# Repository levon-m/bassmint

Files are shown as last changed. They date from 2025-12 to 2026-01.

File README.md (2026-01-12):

# BassMINT

Bass (M)ount for (I)nfrared (N)ote (T)ranscription is a device built with the Teensy 4.0 that slides onto your bass guitar bridge and streams monophonic tablature in real-time via MIDI. This information can be utilized by software like DAW plugins to create practice, transcription, or education tools. The device currently only supports 4-string bass guitars with the Fender Jazz-style bridge, with up to 24 frets.

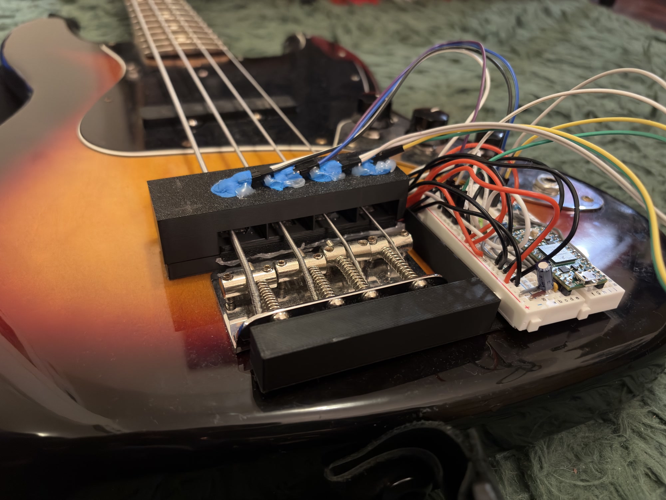
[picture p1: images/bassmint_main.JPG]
BassMINT Device


## Why?

Bass guitar is tricky because:
- Low frequencies need bigger analysis windows
- Strings vibrate sympathetically and create false triggers
- The same pitch can exist on different strings, so you need to know which string is actually being played

BassMINT uses OPT101 optical sensors (one per string) that are used in a two-phase system:
1. **String detection** - Track each string's envelope to know which one you just plucked
2. **Pitch detection** - The string vibration modulates the light beam, so the same signal tells us the pitch

## Hardware

- **Teensy 4.0** - The brain (600MHz ARM Cortex-M7)
- **4x OPT101 sensors** - One per string for activity and pitch detection
- **4x IR LEDs** - Paired with OPT101s to create the break beam
- **Adafruit MIDI FeatherWing** - Provides hardware MIDI DIN output

## Architecture

### Stage 1: String Activity Detection

OPT101 sensors -> Envelope followers (one per string) -> Active string selection

- Figures out which string you just played based on envelope levels

### Stage 2: Fret Estimation

Active string's OPT101 signal -> High-pass filter (DC removal) -> Low-pass filter (anti-aliasing) -> Decimation (44.1kHz -> 4.4kHz) -> NSDF pitch detection with dual-band analysis -> Bayesian octave tracking -> Frequency + confidence

- Uses the same sensor signal to detect the pitch and map it to a fret
- Splits analysis into low octave (frets 0-11) and high octave (frets 12-24)

### Stage 3: Note Resolution

Active string + Frequency -> Fret lookup (constrained to active string) -> MIDI note

- Combines everything into a final decision: which string, which fret, how confident

### Stage 4: MIDI Output

Note On/Off (channel = string + 1), CC 20 (envelope), CC 21 (state), CC 22 (confidence)

- Each string gets its own MIDI channel for polyphonic tracking

## MIDI Encoding

### Channel-Per-String

Each string gets its own MIDI channel so you can track them independently:

| String | MIDI Channel | Open Note | MIDI Note # |
|---|---|---|---|
| E (0)  | 1 | E1 | 28 |
| A (1)  | 2 | A1 | 33 |
| D (2)  | 3 | D2 | 38 |
| G (3)  | 4 | G2 | 43 |

The MIDI note number is just the open string note plus the fret number.

### Control Changes

Each channel also sends some extra info via CC messages:

| CC | Name | Range | Description |
|----|---|---|---|
| 20 | Envelope | 0-127 | How loud the string is |
| 21 | State | 0/64  | Is the string active? (0=idle, 64=active)|
| 22 | Confidence | 0-127 | How confident the pitch detector is |

## Building

### What You Need

- CMake 3.19 or newer
- Ninja build system
- ARM GNU Toolchain (`arm-none-eabi-gcc`)
- Teensy Loader for flashing

### Build

```bash
# Configure (CMakeLists.txt will auto-detect your Teensy cores)
cmake -B build -G Ninja

# Build
cmake --build build

# The output is build/BassMINT.hex
```

If it can't find your Teensy cores automatically, point it there:

```bash
cmake -DTEENSY_PATH="C:/Program Files (x86)/Arduino/hardware/teensy/avr" -B build -G Ninja
```

### Flash

Open Teensy Loader GUI and flash `build/BassMINT.hex`

## Configuration

Main settings in [src/hal/BoardConfig.h](src/hal/BoardConfig.h):

```cpp
static constexpr float SampleRate = 44100.0f;       // Audio sample rate
```

DSP parameters are in their respective headers:

- [OctaveFretEstimator.h](src/dsp/OctaveFretEstimator.h): NSDF confidence threshold (0.6), frequency bands for octave tracking
- [StringActivity.h](src/dsp/StringActivity.h): Attack/release thresholds for string detection (0.1/0.05)
- [EnvelopeFollower.h](src/dsp/EnvelopeFollower.h): Attack/release times (5ms/100ms)

### Debug Output

Enable debugging in [BoardConfig.h](src/hal/BoardConfig.h):

```cpp
static constexpr bool DebugEnabled = true;
static constexpr bool TeleplotMode = false;  // false = text mode, true = graph mode
static constexpr uint32_t DebugOutputHz = 60;  // Update rate for Teleplot
```

**Text mode** (TeleplotMode = false): Prints active string changes to Serial

**Teleplot mode** (TeleplotMode = true): Sends raw ADC values over Serial in Teleplot format:

- `adc_E`, `adc_A`, `adc_D`, `adc_G` - Raw normalized ADC readings (0-1)

Use the [Teleplot VSCode extension](https://marketplace.visualstudio.com/items?itemName=niceprogrammer.teleplot) to visualize.

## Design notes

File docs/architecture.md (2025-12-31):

# BassMINT Architecture

This document describes the detailed architecture of the BassMINT bass guitar MIDI interface.

## System Overview

BassMINT operates as a real-time signal processing pipeline on the Teensy 4.0 microcontroller. The system processes audio at 44.1kHz, with pitch estimates produced every ~23ms (50% overlap on 2048-sample frames).

## Hardware Layer

### Sensors

**OPT101 Break-Beam Sensors (A5-A8)**

- Integrated photodiode + transimpedance amplifier
- Paired with IR LEDs for per-string detection
- DC output varies with string position
- String vibration creates AC component proportional to activity
- Same signal used for both string detection (envelope) and pitch detection (waveform)

### ADC Configuration

- 12-bit resolution (0-4095)
- Hardware averaging (4 samples) for noise reduction
- ~100kHz effective sample rate per channel
- Reading order: strings 0-3 (E, A, D, G) in sequence

## Software Architecture

### Module Hierarchy

```text
main.cpp
    └── App
        ├── AdcDriver (HAL)
        ├── LedDriver (HAL)
        ├── MidiOutput (HAL)
        ├── StringActivity (DSP)
        │   └── EnvelopeFollower (DSP) x4
        ├── PitchDetector (DSP)
        └── StringFretResolver (App)
            ├── NoteTables (Core)
            ├── NoteMapping (Core)
            └── Tuning (Core)
```

### Data Flow

```text
Sample n arrives:
    │
    ├──► OPT101[0..3] ──► EnvelopeFollower ──► StringActivityState
    │                                              │
    │                                              ▼
    │                                        getActiveString()
    │                                              │
    └──► Active String's ──► DC Removal ──► HighPass ──► Window ──► YIN ──┤
         OPT101 Signal                                                     │
                                                                          ▼
                                                                     PitchResult
                                                                          │
                                                                          ▼
                                                        StringFretResolver.resolve()
                                                                          │
                                                                          ▼
                                                                 StringFretDecision
                                                                          │
                                                        ┌─────────────────┴─────────────┐
                                                        ▼                               ▼
                                                   Note On/Off                     CC Messages
                                                   (if changed)                (envelope, state,
                                                                                 confidence)
```

## DSP Module Details

### EnvelopeFollower

Simple asymmetric low-pass filter for amplitude tracking:

```cpp
if (|x| > envelope) {
    envelope = attack * envelope + (1 - attack) * |x|;
} else {
    envelope = release * envelope + (1 - release) * |x|;
}
```

**Parameters:**

- Attack: 5ms (coefficient ~0.9973 at 44.1kHz)
- Release: 100ms (coefficient ~0.99977)

### StringActivity

Maintains state for all 4 strings:

**State Machine (per string):**

```text
        ┌──────────────────────────────────────┐
        │                                      │
        ▼                                      │
    ┌───────┐    envelope > attackThresh   ┌───────┐
    │ IDLE  │ ─────────────────────────►   │ACTIVE │
    └───────┘                               └───────┘
        ▲                                      │
        │     envelope < releaseThresh         │
        └──────────────────────────────────────┘
```

**Active String Selection:**

1. Find all strings in ACTIVE state
2. Select string with highest envelope
3. Tie-breaker: most recent state transition wins

### PitchDetector

YIN algorithm implementation optimized for bass:

**Input Signal Processing:**

1. Read active string's OPT101 sample
2. Convert from 0-1 to -1 to +1 range (remove DC offset)
3. High-pass filter (20Hz cutoff) - removes residual DC and subsonic rumble

**Frame Processing:**

1. Hann window - reduces spectral leakage
2. Difference function - autocorrelation variant
3. CMNDF - cumulative mean normalized difference
4. Threshold search - find first dip below threshold
5. Parabolic interpolation - sub-sample precision

**Bass Optimizations:**

- Frequency range: 30-300 Hz
- minLag = sampleRate / 300 = 147 samples
- maxLag = sampleRate / 30 = 1470 samples
- Frame size: 2048 samples (~46ms) - captures ~1.5 cycles at 30Hz

## Core Module Details

### Tuning

Standard 4-string bass tuning (E-A-D-G):

| String | Note | Frequency | MIDI Note |
|---|---|---|---|
| 0 | E1 | 41.20 Hz | 28 |
| 1 | A1 | 55.00 Hz | 33 |
| 2 | D2 | 73.42 Hz | 38 |
| 3 | G2 | 98.00 Hz | 43 |

### NoteTables

Pre-computed frequency table for all frets (0-24) on all strings:

```text
f(string, fret) = openFrequency[string] * 2^(fret/12)
```

Generated at startup to avoid runtime calculation.

### NoteMapping

Maps detected frequency to nearest fret:

```cpp
FretMatch findNearestFret(float hz, size_t string) {
    for (fret = 0; fret <= 24; fret++) {
        cents = 1200 * log2(hz / table[string][fret]);
        if (|cents| < bestCents) {
            bestFret = fret;
            bestCents = |cents|;
        }
    }
    return {bestFret, cents};
}
```

Rejects matches > 100 cents (1 semitone) from any valid fret.

### StringFretResolver

Combines string activity and pitch detection:

```cpp
resolve() {
    if (!pitch.isValid || pitch.confidence < threshold)
        return nullopt;

    activeString = getActiveString();
    if (!activeString)
        return nullopt;

    fret = findNearestFret(pitch.hz, activeString);
    if (!fret.isValid)
        return nullopt;

    return StringFretDecision{activeString, fret, ...};
}
```

## HAL Module Details

### AdcDriver

Direct register access for IMXRT1062 ADC:

- Single-ended mode
- 12-bit resolution
- Hardware averaging (configurable 1-32)
- ~10us per conversion

**Pin Mapping:**

```cpp
// OPT101 sensors (string detection + pitch detection)
Opt101Pins[4] = {22, 21, 20, 19};  // A8, A7, A6, A5 for E, A, D, G
```

### MidiOutput

Hardware MIDI DIN output via Serial2:

**Standard MIDI 1.0 Format:**

```text
[Status][Data1][Data2]
    │       │      └── Data byte 2 (0-127)
    │       └── Data byte 1 (0-127)
    └── Status byte (0x80-0xFF)
```

**Status Bytes:**

- 0x80-0x8F: Note Off (channel 1-16)
- 0x90-0x9F: Note On (channel 1-16)
- 0xB0-0xBF: Control Change (channel 1-16)

## App Module

### Main Loop Timing

Uses ARM cycle counter for precise sample rate:

```cpp
while (true) {
    uint32_t now = ARM_DWT_CYCCNT;
    if ((now - lastCycle) >= cyclesPerSample) {
        lastCycle = now;
        app.update();
    }
}
```

At 600MHz CPU, 44.1kHz sample rate:

- cyclesPerSample = 600,000,000 / 44,100 = 13,605 cycles
- ~22.7us between samples

### Note Management

State machine for MIDI note output:

```text
                      ┌─────────────────────────┐
                      │                         │
        resolve()     ▼     resolve()          │
        returns    ┌──────┐  returns           │
        nullopt    │ OFF  │  decision          │
       ┌───────────│      │◄───────────────────┤
       │           └──────┘                    │
       │              │                        │
       │              │ resolve() returns      │
       │              │ new decision           │
       │              ▼                        │
       │           ┌──────┐                    │
       │           │  ON  │────────────────────┘
       └──────────►│      │  same note continues
                   └──────┘
                      │
                      │ resolve() returns
                      │ different note
                      ▼
              [Note Off old, Note On new]
```

## Performance Considerations

### CPU Budget (per sample @ 44.1kHz)

| Component | Estimated Cycles |
|---|---|
| ADC reads (4 channels) | ~800 |
| Envelope followers (4x) | ~200 |
| High-pass filter | ~50 |
| Buffer management | ~100 |
| **Total per sample** | **~1150** |

| Component | Per-frame (~23ms) |
|---|---|
| Hann window | ~2000 |
| Difference function | ~4M |
| CMNDF | ~3000 |
| Tau search | ~1500 |
| **Total per frame** | **~4M** |

With 600MHz CPU and 1000 samples per frame:

- Per-sample budget: 13,605 cycles x 1000 = 13.6M cycles
- Available for pitch detection: ~9M cycles
- Actual usage: ~4M cycles (comfortable margin)

### Memory Usage

| Component | Size |
|---|---|
| Input buffer | 4096 x 4 = 16KB |
| Difference buffer | 2048 x 4 = 8KB |
| CMNDF buffer | 2048 x 4 = 8KB |
| Window coefficients | 4096 x 4 = 16KB |
| Note tables | 4 x 25 x 4 = 400B |
| Stack | ~2KB |
| **Total** | **~50KB** |

Teensy 4.0 has 512KB DTCM - plenty of headroom.

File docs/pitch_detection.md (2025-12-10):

# Pitch Detection in BassMINT

This document describes the YIN pitch detection algorithm as implemented in BassMINT, with specific optimizations for bass guitar.

## Why YIN?

YIN (named after the Yin-Yang symbol) is a time-domain pitch detection algorithm developed by Alain de Cheveigné and Hideki Kawahara. It's particularly well-suited for bass guitar because:

1. **Time-domain** - Works well with low frequencies without requiring long FFT windows
2. **Monophonic** - Optimized for single-pitch sources
3. **Low latency** - Can produce estimates with moderate frame sizes
4. **Robust** - Handles harmonic content well, reducing octave errors

## Algorithm Overview

YIN consists of several steps:

### Step 1: Difference Function

The core of YIN is a modified autocorrelation function called the "difference function":

```
d(τ) = Σ (x[n] - x[n + τ])²
       n=0 to W-1
```

Where:
- `x[n]` is the input signal
- `τ` (tau) is the lag (candidate period)
- `W` is the integration window size

This function measures how different the signal is from a time-shifted version of itself. For a periodic signal, `d(τ)` will have minima at τ = period, 2×period, etc.

### Step 2: Cumulative Mean Normalized Difference (CMNDF)

The raw difference function has a problem: `d(0) = 0` always, which would falsely indicate infinite frequency. CMNDF normalizes the difference function:

```
d'(τ) = 1,                           if τ = 0
        d(τ) / [(1/τ) Σ d(j)],       if τ > 0
                      j=1 to τ
```

This normalization:
- Sets d'(0) = 1 (avoiding false minimum)
- Makes values comparable across different lags
- Typically produces values near 0 for true periods

### Step 3: Absolute Threshold

Rather than finding the global minimum (which might be an octave error), YIN uses a threshold:

1. Search from minLag to maxLag
2. Find the first τ where d'(τ) < threshold
3. Within that dip, find the local minimum

Default threshold: 0.15 (lower = stricter detection)

### Step 4: Parabolic Interpolation

The discrete τ value is refined using parabolic interpolation through three points:

```
τ_refined = τ + (d'[τ-1] - d'[τ+1]) / (2 × (d'[τ-1] - 2×d'[τ] + d'[τ+1]))
```

This provides sub-sample precision, improving frequency accuracy.

### Step 5: Frequency Calculation

```
frequency = sampleRate / τ_refined
```

## Bass Guitar Optimizations

### Frequency Range

Bass guitar fundamentals span approximately:
- Low E1: 41.2 Hz
- High G at 24th fret: ~392 Hz

We use a conservative range:
- **Minimum frequency: 30 Hz** (allows for drop tuning, pitch detection below fundamental)
- **Maximum frequency: 300 Hz** (captures most played notes, excludes harmonics)

This translates to lag bounds:
```cpp
minLag = sampleRate / maxFrequency = 44100 / 300 = 147 samples
maxLag = sampleRate / minFrequency = 44100 / 30 = 1470 samples
```

### Frame Size

Bass frequencies require larger analysis windows:
- At 30 Hz, one period = 33.3 ms = 1470 samples
- Recommended: At least 2-3 periods for reliable detection
- **Frame size: 2048 samples (~46 ms at 44.1 kHz)**

This captures ~1.5 periods at 30 Hz, sufficient for YIN with proper windowing.

### Pre-processing

**High-Pass Filter (20 Hz cutoff)**

Removes:
- DC offset from ADC
- Subsonic rumble from handling
- Mechanical vibration below musical range

Implementation: Simple 1-pole IIR filter
```cpp
y[n] = α × (y[n-1] + x[n] - x[n-1])
α = RC / (RC + dt) where RC = 1/(2π × 20Hz)
```

**Hann Window**

Applied before difference function to reduce spectral leakage:
```cpp
w[n] = 0.5 × (1 - cos(2π × n / (N-1)))
```

The window tapers the frame edges to zero, preventing discontinuities from introducing spurious frequencies.

### Overlap Processing

Frames overlap by 50% (1024 samples = ~23 ms):
- New estimate every 23 ms
- Smooth tracking of pitch changes
- Balance between latency and stability

## Confidence Metric

YIN provides a natural confidence measure:

```cpp
confidence = 1 - d'(τ_best)
```

Where d'(τ_best) is the CMNDF value at the detected period.

Interpretation:
- confidence ≈ 1.0: Very clean periodic signal
- confidence ≈ 0.85: Good detection, some noise/harmonics
- confidence < 0.5: Unreliable, possibly noise or non-periodic

BassMINT uses **minimum confidence threshold of 0.5** by default.

## Implementation Details

### Memory Layout

```cpp
// Input buffer (ring buffer with overlap)
float inputBuffer_[4096];

// Working buffers (reused per frame)
float differenceBuffer_[2048];  // Half frame size
float cmndfBuffer_[2048];

// Pre-computed window
float window_[4096];
```

### Difference Function Optimization

The naive O(N²) implementation can be optimized:

**Naive:**
```cpp
for (tau = 0; tau < N/2; tau++) {
    for (i = 0; i < N/2; i++) {
        diff = frame[i] - frame[i + tau];
        d[tau] += diff * diff;
    }
}
```

**Optimized (using autocorrelation):**
```
d(τ) = r(0) + r(τ) - 2×r(τ)

where r(τ) = Σ x[n] × x[n+τ]
```

The autocorrelation can be computed via FFT for O(N log N) complexity.

However, for our frame size (2048) and lag range (147-1470), the direct method is fast enough on Cortex-M7 at 600 MHz.

### Edge Cases

**No Valid Period Found:**
- If no d'(τ) < threshold in the lag range
- Return confidence = 0, indicating unreliable estimate

**Octave Errors:**
- YIN's threshold search naturally prefers the fundamental
- First dip below threshold is usually the true period
- Searching from short to long lags prevents octave-up errors

**Silence/Noise:**
- Low signal energy produces low confidence
- Envelope threshold in StringActivity gates pitch detection
- Only run pitch detection when string is active

## Performance Characteristics

### Latency

Total latency from pluck to MIDI:
- Frame fill: 46 ms (worst case, first frame)
- Processing: ~0.5 ms
- USB MIDI: ~1 ms
- **Total: ~48 ms** (worst case)

Average latency with overlap: ~24 ms

### Accuracy

For a well-tuned bass with clean technique:
- Fundamental detection: >95% accuracy
- Typical error: <10 cents
- Octave errors: <1% (with threshold search)

### CPU Usage

At 44.1 kHz, 2048-sample frames, 50% overlap:
- Difference function: ~4M cycles per frame
- CMNDF: ~3000 cycles
- Tau search: ~1500 cycles
- Total: ~4M cycles every 23 ms
- CPU utilization: ~3% of 600 MHz Cortex-M7

## Tuning Parameters

Key parameters in `PitchDetector.h`:

```cpp
// Frequency range
static constexpr float MinFrequency = 30.0f;
static constexpr float MaxFrequency = 300.0f;

// Detection threshold (lower = stricter)
static constexpr float DefaultThreshold = 0.15f;
```

**Adjusting Threshold:**
- Lower (0.10): More reliable, may miss quiet notes
- Higher (0.20): More sensitive, may have more false positives

**Adjusting Frequency Range:**
- Extend MinFrequency for drop tuning (e.g., 25 Hz for Drop A)
- Extend MaxFrequency for higher frets or piccolo bass

## References

1. de Cheveigné, A., & Kawahara, H. (2002). "YIN, a fundamental frequency estimator for speech and music." Journal of the Acoustical Society of America, 111(4), 1917-1930.

2. Brossier, P. (2007). "Automatic Annotation of Musical Audio for Interactive Applications." PhD thesis, Queen Mary University of London. (aubio implementation)

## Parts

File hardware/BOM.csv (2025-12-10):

Item | Quantity | RefDes | MFR / Source | MFR PN / Link | DigiKey PN | ~Price
Seeed XIAO RP2040 | 1 |  | Seeed Technology Co., Ltd | 102010428 | 1597-102010428-ND | $4.68
MIDI FeatherWing kit | 1 |  | Adafruit Industries LLC | 4740 | 1528-4740-ND | $6.95
Photodiode + TIA ICs | 4 |  | Texas Instruments | OPT101P | 296-23090-5-ND | $36.24
940nm IR LEDs | 4 |  | Vishay Semiconductor Opto Division | TSAL6400 | 751-1205-ND | $1.96
0.1uF Capacitors | 4 |  | KEMET | C315C104K5R5TA | 399-C315C104K5R5TA-ND | $1.88
10uF Capacitors | 2 |  | Panasonic Electronic Components | ECA-1EM100 | P5148-ND | $0.40
9V Battery | 1 |  | Panasonic Energy | 6LF22XWA/B | P687-ND | $2.32
9V Battery Connector | 1 |  | Keystone Electronics | 233 | 36-233-ND | $0.54
1/4" Black Heatshrink | 1 |  | 3M | FP301-1/4-48"-BLACK-200 PCS | 3M161319-ND | $3.85
4x2 IC Dip Socket | 4 |  | On Shore Technology Inc. | ED08DT | ED3044-5-ND | $0.76
Rocker Switch | 1 |  | E-Switch | RA11131121 | EG5617-ND | $0.71
330 Ohm Resistors | 4 |  | Stackpole Electronics Inc | CF14JT330R | CF14JT330RCT-ND | $0.40
5V Buck Converter | 1 |  | Amazon | https://www.amazon.com/dp/B0BVFTSSSC |  | $8.69
 |  |  |  |  |  | $70.00

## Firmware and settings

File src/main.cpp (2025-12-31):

/**
 * BassMINT - Bass Guitar MIDI Interface using Teensy 4.0
 *
 * Hardware:
 * - Teensy 4.0 (IMXRT1062, 600MHz ARM Cortex-M7)
 * - 4x OPT101 + IR LED break-beam sensors for string activity and pitch detection
 * - MIDI DIN output via Serial2
 *
 * Pin assignments are configured in hal/BoardConfig.h
 */

#include <Arduino.h>
#include "app/App.h"
#include "hal/BoardConfig.h"

using namespace bassmint;

// Cycles per sample for 44.1kHz timing
// At 600MHz: 600,000,000 / 44,100 = 13,605 cycles per sample
static constexpr uint32_t CYCLES_PER_SAMPLE =
    F_CPU / static_cast<uint32_t>(BoardConfig::SampleRate);

// Global application instance
static App* gApp = nullptr;

void setup() {
    // Enable ARM cycle counter for precise sample-rate timing
    // These are standard ARM Cortex-M debug registers
    ARM_DEMCR |= ARM_DEMCR_TRCENA;      // Enable trace
    ARM_DWT_CTRL |= ARM_DWT_CTRL_CYCCNTENA;  // Enable cycle counter

    // Initialize Serial for Teleplot debug output
    if constexpr (BoardConfig::DebugEnabled) {
        Serial.begin(BoardConfig::DebugBaudRate);
        Serial.println("BassMINT starting...");
    }

    // Create and initialize application
    static App application;
    gApp = &application;
    gApp->init();

    if constexpr (BoardConfig::DebugEnabled) {
        Serial.println("BassMINT ready");
    }
}

void loop() {
    if (gApp == nullptr) return;

    // Wait until enough cycles have passed for next sample
    static uint32_t lastCycle = 0;
    uint32_t now = ARM_DWT_CYCCNT;

    if ((now - lastCycle) >= CYCLES_PER_SAMPLE) {
        lastCycle = now;
        gApp->update();
    }
}

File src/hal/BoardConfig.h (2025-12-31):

#pragma once

#include <cstdint>
#include <cstddef>

namespace bassmint {

/**
 * Centralized hardware pin configuration for BassMINT
 *
 * Edit this file to match your wiring setup.
 * All pin assignments are Teensy 4.0 pin numbers.
 */
namespace BoardConfig {

    // Number of strings
    static constexpr size_t NumStrings = 4;

    // =========================================================================
    // OPT101 SENSORS (String Detection + Pitch Detection)
    // =========================================================================
    // One OPT101 photodiode per string, analog outputs
    // Used for both string activity detection and pitch detection
    // String order: E(0), A(1), D(2), G(3)
    static constexpr uint8_t Opt101Pins[NumStrings] = {
        22,  // A8 - String 0 (E)
        21,  // A7 - String 1 (A)
        20,  // A6 - String 2 (D)
        19   // A5 - String 3 (G)
    };

    // =========================================================================
    // IR LED CONTROL (Paired with OPT101 sensors)
    // =========================================================================
    // Digital outputs to control IR LEDs for break-beam sensing
    // Each IR LED pairs with corresponding OPT101 sensor
    static constexpr uint8_t IrLedPins[NumStrings] = {
        2,   // String 0 (E) IR LED
        3,   // String 1 (A) IR LED
        4,   // String 2 (D) IR LED
        5    // String 3 (G) IR LED
    };

    // IR LED active state (1 = on, 0 = on for active-low drivers)
    static constexpr uint8_t IrLedActiveState = 1;

    // =========================================================================
    // MIDI OUTPUT (via Adafruit MIDI FeatherWing)
    // =========================================================================
    // Hardware MIDI DIN output via Serial2
    static constexpr uint8_t MidiTxPin = 8;   // Serial2 TX (TX2)
    static constexpr uint8_t MidiRxPin = 7;   // Serial2 RX (RX2)
    static constexpr uint32_t MidiBaudRate = 31250;     // Standard MIDI baud rate

    // =========================================================================
    // STATUS LED (Optional)
    // =========================================================================
    // Built-in LED for status indication
    static constexpr uint8_t StatusLedPin = 13;  // Teensy built-in LED

    // =========================================================================
    // ADC CONFIGURATION
    // =========================================================================
    static constexpr uint8_t AdcResolution = 12;          // 12-bit ADC
    static constexpr uint16_t AdcMaxValue = (1 << 12) - 1; // 4095
    static constexpr uint8_t AdcAveraging = 4;            // Hardware averaging samples
    static constexpr float VRef = 3.3f;                   // Reference voltage

    // =========================================================================
    // TIMING CONFIGURATION
    // =========================================================================
    static constexpr float SampleRate = 44100.0f;         // Audio sample rate (Hz)
    static constexpr size_t PitchFrameSize = 2048;        // Pitch detection frame size

    // =========================================================================
    // DEBUG CONFIGURATION
    // =========================================================================
    static constexpr bool DebugEnabled = true;
    static constexpr uint32_t DebugBaudRate = 115200;
    static constexpr uint32_t DebugOutputHz = 60;         // How often to send Teleplot data

    // Debug mode: true = Teleplot graphs, false = text messages (active string changes)
    static constexpr bool TeleplotMode = false;

} // namespace BoardConfig
} // namespace bassmint

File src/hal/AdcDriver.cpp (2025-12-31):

#include "AdcDriver.h"
#include <Arduino.h>

namespace bassmint {

void AdcDriver::init() {
    // Configure ADC resolution
    analogReadResolution(BoardConfig::AdcResolution);

    // Set averaging for smoother reads
    analogReadAveraging(averaging_);

    // Disable digital input keeper on all analog pins to prevent loading
    // high-impedance sources (OPT101 outputs).
    // The Teensy 4.0 GPIO keeper acts like ~100k pull and creates a resistor
    // divider that drags the ADC node away from the intended bias voltage.
    for (size_t i = 0; i < NumStrings; ++i) {
        pinMode(BoardConfig::Opt101Pins[i], INPUT_DISABLE);
    }
}

uint16_t AdcDriver::readAdc(uint8_t pin) {
    return analogRead(pin);
}

float AdcDriver::readStringSample(size_t stringIndex) {
    uint16_t raw = readStringRaw(stringIndex);

    // OPT101 output is DC (0 to VRef based on light intensity)
    float normalized = static_cast<float>(raw) / static_cast<float>(BoardConfig::AdcMaxValue);
    return normalized;
}

uint16_t AdcDriver::readStringRaw(size_t stringIndex) {
    if (stringIndex >= NumStrings) {
        return 0;
    }
    return readAdc(BoardConfig::Opt101Pins[stringIndex]);
}

void AdcDriver::setAveraging(uint8_t samples) {
    averaging_ = (samples > 32) ? 32 : ((samples < 1) ? 1 : samples);
    analogReadAveraging(averaging_);
}

} // namespace bassmint

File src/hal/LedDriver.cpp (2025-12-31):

#include "LedDriver.h"
#include <Arduino.h>

namespace bassmint {

void LedDriver::init() {
    // Configure all IR LED pins as outputs
    for (size_t i = 0; i < NumLeds; ++i) {
        pinMode(BoardConfig::IrLedPins[i], OUTPUT);
        // Start with LEDs on (normal operation)
        turnOn(i);
    }
}

void LedDriver::turnOn(size_t index) {
    if (index >= NumLeds) return;

    digitalWrite(BoardConfig::IrLedPins[index], BoardConfig::IrLedActiveState);
    ledStates_[index] = true;
}

void LedDriver::turnOff(size_t index) {
    if (index >= NumLeds) return;

    uint8_t offState = (BoardConfig::IrLedActiveState == 1) ? 0 : 1;
    digitalWrite(BoardConfig::IrLedPins[index], offState);
    ledStates_[index] = false;
}

void LedDriver::allOn() {
    for (size_t i = 0; i < NumLeds; ++i) {
        turnOn(i);
    }
}

void LedDriver::allOff() {
    for (size_t i = 0; i < NumLeds; ++i) {
        turnOff(i);
    }
}

void LedDriver::set(size_t index, bool on) {
    if (on) {
        turnOn(index);
    } else {
        turnOff(index);
    }
}

void LedDriver::toggle(size_t index) {
    if (index >= NumLeds) return;

    set(index, !ledStates_[index]);
}

bool LedDriver::isOn(size_t index) const {
    if (index >= NumLeds) return false;
    return ledStates_[index];
}

void LedDriver::initStatusLed() {
    pinMode(BoardConfig::StatusLedPin, OUTPUT);
    setStatusLed(false);
}

void LedDriver::setStatusLed(bool on) {
    digitalWrite(BoardConfig::StatusLedPin, on ? 1 : 0);
    statusLedState_ = on;
}

void LedDriver::toggleStatusLed() {
    setStatusLed(!statusLedState_);
}

} // namespace bassmint
